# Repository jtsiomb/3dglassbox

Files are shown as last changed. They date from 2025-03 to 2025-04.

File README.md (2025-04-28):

3dglassbox - interface for 3D shutter glasses
=============================================
This is a versatile interface for driving 3D shutter glasses from a variety of
stereo sync sources.

Supported sync sources:
  - SGI 3-pin mini-DIN stereo port
  - SGI DE9 stereo port (IMPACT graphics)
  - VESA 3-pin mini-DIN stereo port
  - Frame-sequencial vsync toggle

Supported shutter glasses:
  - StereoGraphics CrystalEyes (IR)
  - ASUS VR100 (wired)

**Current status**: Under development. Not ready for use.

License
-------
Copyright (C) 2025 John Tsiombikas <nuclear@mutantstargoat.com>

You are free to use, reproduce, modify, and redistribute any part of this
project, provided you make any derivative work you release, freely available
under the same terms.

Both hardware designs, and software parts of this project, are released under
the terms of the GNU General Public License v3, or at your option any later
version published by the Free Software Foundation. See `LICENSE` for details.

To comply with the license, when releasing derivative hardware designs, you must
provide the full EDA project files, and of course firmware/software source code.
Releasing only images of schematics, gerbers, and firmware binaries is *not*
sufficient for compliance.

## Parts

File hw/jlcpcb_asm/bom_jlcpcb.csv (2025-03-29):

Comment | Designator | Footprint | LCSC
0.33uF | C1,C2 | Capacitor_SMD:CP_Elec_4x5.4 | C264238
0.1uF | C3,C4,C5,C6,C8 | Capacitor_SMD:C_0805_2012Metric_Pad1.18x1.45mm_HandSolder | C49678
IR LED | D1,D2,D3,D4,D5,D6,D7,D8,D9,D10,D11,D12,D13,D14,D15,D16 | LED_THT:LED_D3.0mm_Horizontal_O1.27mm_Z2.0mm
SS34 | D17 | Diode_SMD:D_SMA_Handsoldering
LED | D18 | LED_THT:LED_D5.0mm | C2895492
SGI stereo | J1 | 3dglassbox:minidin3 | C20611697
SGI Impact stereo | J2 | Connector_Dsub:DSUB-9_Male_Horizontal_P2.77x2.84mm_EdgePinOffset7.70mm_Housed_MountingHolesOffset9.12mm | C7498157
12v DC | J3 | Connector_BarrelJack:BarrelJack_Horizontal | C962225
AVR-ISP-6 | J4 | Connector_IDC:IDC-Header_2x03_P2.54mm_Vertical | C4749192
VESA | J6 | 3dglassbox:minidin3 | C20611697
VSYNC | J7 | Connector_Coaxial:BNC_TEConnectivity_1478035_Horizontal | C521209
ASUS VR-100 | J8 | Connector_Audio:Jack_3.5mm_CUI_SJ1-3525N_Horizontal | C692542
2N7002 | Q1,Q2 | Package_TO_SOT_SMD:SOT-23 | C8545
220R | R1,R2,R3,R4,R5,R6,R7,R8,R9,R10,R11,R12,R13,R14,R15,R16 | Resistor_SMD:R_0805_2012Metric_Pad1.20x1.40mm_HandSolder | C17557
4K7 | R17,R18,R19,R20 | Resistor_SMD:R_0805_2012Metric_Pad1.20x1.40mm_HandSolder | C17673
1K | R21 | Resistor_SMD:R_0805_2012Metric_Pad1.20x1.40mm_HandSolder | C17513
vsync_flip | SW1 | Button_Switch_THT:SW_Slide_SPDT_Straight_CK_OS102011MS2Q | C136719
IR HIGH/LOW SW | SW2 | Button_Switch_SMD:SW_SPDT_PCM12 | C431541
syncsrc | SW3 | Button_Switch_THT:SW_Slide_SPDT_Straight_CK_OS102011MS2Q | C136719
POWER SW | SW4 | Button_Switch_SMD:SW_SPDT_PCM12 | C431541
SW_SEL | SW5 | Button_Switch_SMD:SW_Push_1P1T_NO_6x6mm_H9.5mm | C455110
SW_NEXT | SW6 | Button_Switch_SMD:SW_Push_1P1T_NO_6x6mm_H9.5mm | C455110
L7805 | U1 | Package_TO_SOT_SMD:TO-252-3_TabPin2 | C21706
ATtiny13A-SS | U2 | Package_SO:SOIC-8_3.9x4.9mm_P1.27mm | C40382
LM358 | U3 | Package_SO:SOIC-8_3.9x4.9mm_P1.27mm | C7950
74HC73 | U4 | Package_SO:SO-14_3.9x8.65mm_P1.27mm | C350539

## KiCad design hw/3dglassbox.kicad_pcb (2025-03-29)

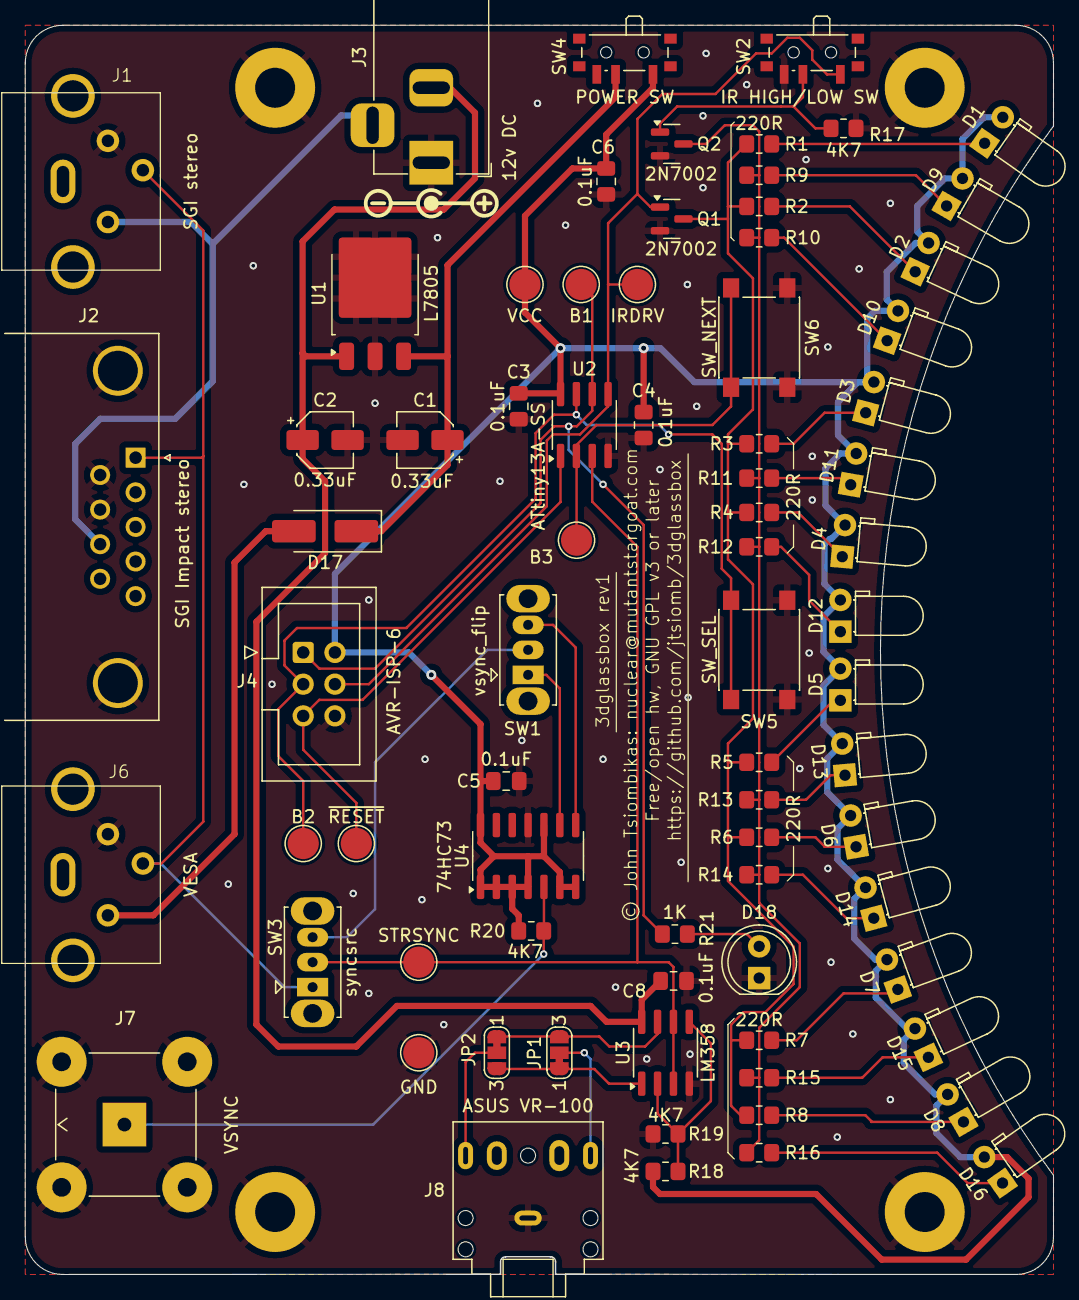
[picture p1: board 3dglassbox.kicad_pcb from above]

Board: 2 copper layers, 82.3 x 100.0 mm, 78 parts (0 on the bottom side), 42 nets.

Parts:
B1, B2, B3: TestPoint; TestPoint_Pad_D2.5mm
C1, C2: 0.33uF; CP_Elec_4x5.4
C3, C4, C5, C6, C8: 0.1uF; C_0805_2012Metric_Pad1.18x1.45mm_HandSolder
D1, D2, D3, D4, D5, D6, D7, D8, D9, D10, D11, D12, D13, D14, D15, D16: IR LED; LED_D3.0mm_Horizontal_O1.27mm_Z2.0mm
D17: SS34; D_SMA_Handsoldering
D18: LED; LED_D5.0mm
GND: TestPoint; TestPoint_Pad_D2.5mm
H1, H2, H3, H4: MountingHole_Pad; MountingHole_3.2mm_M3_Pad
IRDRV: TestPoint; TestPoint_Pad_D2.5mm
J1: SGI stereo; minidin3
J2: SGI Impact stereo; DSUB-9_Male_Horizontal_P2.77x2.84mm_EdgePinOffset7.70mm_Hou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
J3: 12v DC; BarrelJack_Horizontal
J4: AVR-ISP-6; IDC-Header_2x03_P2.54mm_Vertical
J6: VESA; minidin3
J7: VSYNC; BNC_TEConnectivity_1478035_Horizontal
J8: ASUS VR-100; Jack_3.5mm_CUI_SJ1-3525N_Horizontal
JP1: JPOL1; SolderJumper-3_P1.3mm_Bridged12_RoundedPad1.0x1.5mm_NumberL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
JP2: JPOL2; SolderJumper-3_P1.3mm_Bridged12_RoundedPad1.0x1.5mm_NumberL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
Q1, Q2: 2N7002; SOT-23
R1, R2, R3, R4, R5, R6, R7, R8, R9, R10, R11, R12, R13, R14, R15, R16: 220R; R_0805_2012Metric_Pad1.20x1.40mm_HandSolder
R17, R18, R19, R20: 4K7; R_0805_2012Metric_Pad1.20x1.40mm_HandSolder
R21: 1K; R_0805_2012Metric_Pad1.20x1.40mm_HandSolder
STRSYNC: TestPoint; TestPoint_Pad_D2.5mm
SW1: vsync_flip; SW_Slide_SPDT_Straight_CK_OS102011MS2Q
SW2: IR HIGH/LOW SW; SW_SPDT_PCM12
SW3: syncsrc; SW_Slide_SPDT_Straight_CK_OS102011MS2Q
SW4: POWER SW; SW_SPDT_PCM12
SW5: SW_SEL; SW_Push_1P1T_NO_6x6mm_H9.5mm
SW6: SW_NEXT; SW_Push_1P1T_NO_6x6mm_H9.5mm
U1: L7805; TO-252-3_TabPin2
U2: ATtiny13A-SS; SOIC-8_3.9x4.9mm_P1.27mm
U3: LM358; SOIC-8_3.9x4.9mm_P1.27mm
U4: 74HC73; SO-14_3.9x8.65mm_P1.27mm
VCC: TestPoint; TestPoint_Pad_D2.5mm

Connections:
+5V: C1.1, D17.1 (K), SW4.2 (B), U1.3 (OUT)
+12V: C2.1, C8.1, J3.2, U1.1 (IN), U3.8 (V+)
/B1: B1.1, J4.1 (MISO), R21.1, U2.6 (PB1)
/B2: B2.1, J4.3 (SCK), SW5.1, U2.7 (PB2)
/B3: B3.1, SW6.1, U2.2 (PB3)
/IRDRV: IRDRV.1, J4.4 (MOSI), Q1.1 (G), SW2.1 (A), U2.5 (PB0)
/STEREOIN: J1.3, J2.1, J6.3, SW3.1 (A)
/STRSYNC: STRSYNC.1, SW3.2 (B), U2.3 (PB4), U3.3 (+), U3.6 (-)
/VSYNC: J7.1 (In), R20.2, U4.5 (C)
/~RESET: J4.5 (~RST), U2.1 (~RESET/PB5)
GND: C1.2, C2.2, C3.2, C4.2, C5.2, C6.2, C8.2, D18.1 (K), GND.1, H1.1, H2.1, H3.1, H4.1, J1.2, J2.0 (PAD), J2.6, J2.7, J3.1, J4.6 (GND), J6.2, J7.2 (Ext), J8.S, Q1.2 (S), Q2.2 (S), R17.1, R19.2, SW2.3 (C), SW5.2, SW6.2, U1.2 (GND), U2.4 (GND), U3.4 (V-), U4.11 (GND)
unnamed: D1.1 (K), R1.1
unnamed: D2.1 (K), R2.1
unnamed: D3.1 (K), R3.1
unnamed: D4.1 (K), R4.1
unnamed: D5.1 (K), R5.1
unnamed: D6.1 (K), R6.1
unnamed: D7.1 (K), R7.1
unnamed: D8.1 (K), R8.1
unnamed: D9.1 (K), R9.1
unnamed: D10.1 (K), R10.1
unnamed: D11.1 (K), R11.1
unnamed: D12.1 (K), R12.1
unnamed: D13.1 (K), R13.1
unnamed: D14.1 (K), R14.1
unnamed: D15.1 (K), R15.1
unnamed: D16.1 (K), R16.1
unnamed: D17.2 (A), J6.1
unnamed: D18.2 (A), R21.2
unnamed: JP1.1 (A), JP2.3 (B), U3.1
unnamed: JP1.3 (B), JP2.1 (A), U3.7
unnamed: J8.T, JP1.2 (C)
unnamed: J8.R, JP2.2 (C)
unnamed: Q1.3 (D), R1.2, R2.2, R3.2, R4.2, R5.2, R6.2, R7.2, R8.2
unnamed: Q2.3 (D), R9.2, R10.2, R11.2, R12.2, R13.2, R14.2, R15.2, R16.2
unnamed: Q2.1 (G), R17.2, SW2.2 (B)
unnamed: SW1.1 (A), U4.9 (Q)
unnamed: SW1.2 (B), SW3.3 (C)
unnamed: SW1.3 (C), U4.8 (~Q)
unnamed: R18.2, R19.1, U3.2 (-), U3.5 (+)
VBUS: J1.1, J2.8, J3.3
VCC: C3.1, C4.1, C5.1, C6.1, D1.2 (A), D2.2 (A), D3.2 (A), D4.2 (A), D5.2 (A), D6.2 (A), D7.2 (A), D8.2 (A), D9.2 (A), D10.2 (A), D11.2 (A), D12.2 (A), D13.2 (A), D14.2 (A), D15.2 (A), D16.2 (A), J4.2 (VCC), R18.1, R20.1, SW4.1 (A), U2.8 (VCC), U4.1 (C), U4.2 (~R), U4.3 (K), U4.4 (VCC), U4.6 (~R), U4.7 (J), U4.10 (K), U4.14 (J), VCC.1

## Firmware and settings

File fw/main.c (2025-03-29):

#include <stdio.h>
#include <stdlib.h>
#include <string.h>
#include <avr/io.h>
#include <avr/interrupt.h>
#include <avr/power.h>
#include <util/delay.h>

/* L: 60usec / R: 120usec */
enum { RIGHT, LEFT = 0x10 };

/* PWM: with prescaler 1, timer ticks are 1us each, so in inverted FastPWM mode,
 * for a pulse of 60us we need a comparison value of simply 256 - 60.
 */
#define PWM_OCR_L	(256 - 60)
#define PWM_OCR_R	(256 - 120)

uint8_t cur_eye, next_eye;

int main(void)
{
	/* B0: PWM output, B4: stereo input */

	DDRB = 0x03;	/* B[0,1] outputs, B[2,5] inputs */
	PORTB = 0xef;	/* disable pullup on B4 */

	power_timer0_enable();

	/* PWM goes to pin 5 (OC0A), Fast PWM, inverted (high pulses) */
	TCCR0A = 0xc3;	/* COM0A0 | COM0A1 | WGM00 | WGM01 */
	/* clock prescaler: 1 */
	TCCR0B = 1;		/* CS00 */
	OCR0A = PWM_OCR_L;

	for(;;) {
		next_eye = PINB & 0x10;
		if(next_eye != cur_eye) {
			OCR0A = next_eye == RIGHT ? PWM_OCR_R : PWM_OCR_L;
			cur_eye = next_eye;
		}
	}

	return 0;
}

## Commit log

2025-03-29 pcb design done
    [3dglassbox.kicad_pcb, 3dglassbox.kicad_sch]
2025-03-29 change portb config to match current schematic (buttons)
2025-03-29 front PCB cutout, to avoid blocking the IR LEDs from below
    [3dglassbox.kicad_pcb]
2025-03-29 added jlcpcb assembly files
    [3dglassbox.kicad_pcb, bom_jlcpcb.csv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]
2025-03-29 let's just commit the gerbers too
    [3dglassbox-B_Cu.gbr, 3dglassbox-B_Mask.gbr, 3dglassbox-B_Paste.gbr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]

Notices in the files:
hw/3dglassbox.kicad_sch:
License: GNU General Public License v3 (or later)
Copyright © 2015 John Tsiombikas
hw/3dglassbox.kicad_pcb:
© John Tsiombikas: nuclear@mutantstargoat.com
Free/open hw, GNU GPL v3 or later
